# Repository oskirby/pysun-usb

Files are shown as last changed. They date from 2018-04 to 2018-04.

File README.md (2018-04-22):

PySUN-USB
=========
The PySUN is a USB dongle for IEEE 802.15.4 Smart Utility Networking protocols. This project is based around
an STM32F4-series microprocessor and the Atmel/Microchip AT86RF215 dual-band IEEE 802.15.4 transceiver. This
board also supports a Micropython programming environment. The two RF bands from the transceiver are combined
into a single antenna port using an RF diplexer.

This board is released as an Open Source Hardware project, including the full PCB design files from KiCAD.

Features
-----------
Attached to the STM32F4 microcontroller, are the following peripherals:
* AT86RF215 connected to SPI2.
* 32Mbit SPI flash connected to SPI1.
* RGB LED connected to PB0, PB1 and PB10.
* Tactile switch connected to BOOT0 and PB7.
* Power/status LED connected to PB6.

Castellated edges are provided, exposing:
* SPI1
* I2C1
* USART1
* RF215 FEA and FEB outputs

Power is provided by a 2MHz synchronous buck regulator and the clock reference is provided from a 26MHz TCXO.

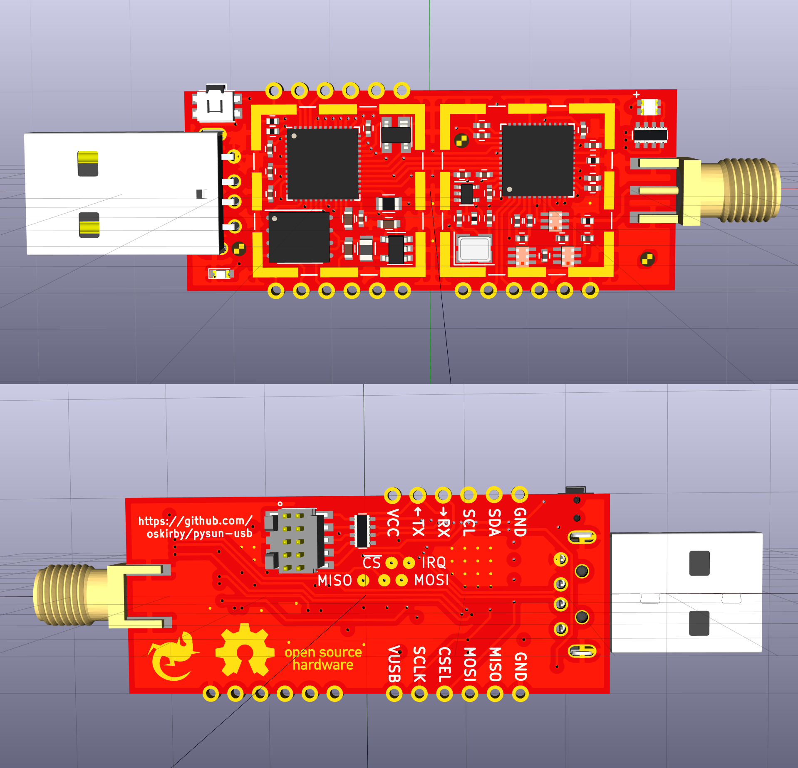
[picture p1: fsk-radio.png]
PySUN PCB Render


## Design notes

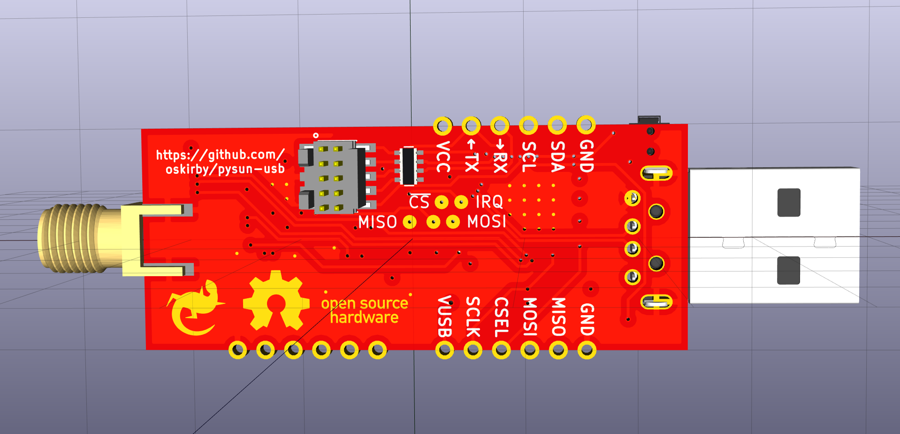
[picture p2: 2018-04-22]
fsk-radio-back.png

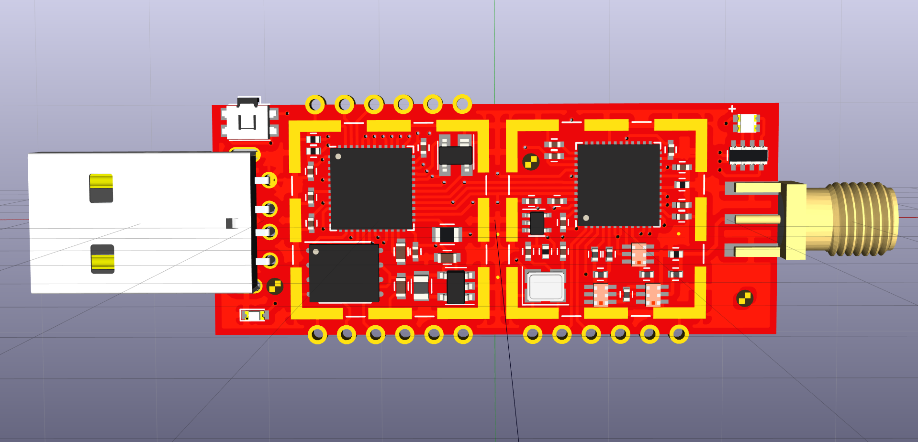
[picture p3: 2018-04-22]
fsk-radio-front.png

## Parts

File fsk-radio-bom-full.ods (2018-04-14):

Designator | Package | Quantity | Value | Manufacturer | Part Number | Substitutions | OPL | Notes
J5,J4 | 16.5mm Square RF Shield | 2 | RF_Shield_One_Piece | TE Connectivity | 2118707-4 | Y
C11,C7,C3 | C_0603 | 3 | 4.7uF | Yageo | CC0603KRX5RGBB475 | Y | 302010111 | Generic 0603 ceramic capacitor. Bulk capacitance for DCDC converter
J1 | CUI-UP2-AH-TH | 1 | USB_A | CUI | UP2-AH-1-TH | Y
IC4 | SOT-353_SC-70-5 | 1 | NC7SZ04 | NXP | NC7SZ04P5X | Y
IC6 | DFN-S-8-1EP_6x5mm_Pitch1.27mm | 1 | W25Q32BVZPIP | Winbond | W25Q32BVZPIP | Y | 310090078 | Generic SPI flash
X1 | Crystal_SMD_3225-4pin_3.2x2.5mm | 1 | TXETBLSANF-26 | Taitien | TXETBLSANF-26.000000 | N
R3,R4 | R_0402 | 2 | 470k | Yageo | RC0402FR-07470KL | Y | 301010069 | Generic 0402 resistor
C9,C15 | C_0402 | 2 | 1nF | Yageo | CC0402KRX7R9BB102 | Y | 302010005 | Generic 0402 ceramic capacitor
L1 | L_0603 | 1 | 2.2uH | TDK | VLF5010ST-2R2M2R0 | Y | 303010086 | 0805 Inductor. Substitutions okay if shielded with rated current >1A and SRF > 25MHz
B9 | Balun_0805 | 1 | 0896BM15E0025 | Johanson Technology | 0896BM15E0025E | N
B24 | Balun_0805 | 1 | 2450FB15A050 | Johanson Technology | 2450FB15A050E | N
C26 | L_0402 | 1 | 0.8pF | Johanson Dielectrics | 500R07S0R8BV4T | Y | 302010021 | 0402 NP0/C0G ceramic capacitor for RF filter
C27, C29 | L_0402 | 2 | 15pF | Johanson Dielectrics | 500R07S150JV4T | Y | 302010041 | 0402 NP0/C0G ceramic capacitor for RF filter
C31,C32 | L_0402 | 2 | 1.8pF | Johanson Dielectrics | 500R07S1R8BV4T | Y |  | 0402 NP0/C0G ceramic capacitor for RF filter
D1 | LED_0606_RGB | 1 | LED_RGB_ANODE | Line-On | LTST-C19HE1WT | Y
IC7 | Balun_0805 | 1 | DPX202700DT | TDK | DPX202700DT-4062A1 | N
L2 | L_0402 | 1 | 5.6nH | Johanson Technology | L-07C5N6SV6T | Y | 303010524 | 0402 inductor for RF filter
RN1 | R_Array_Concave_4x0603 | 1 | 330 | Bourns | CAT16-331J4LF | Y |  | Generic 1206 resistor array
J7 | SMA-Board-Edge | 1 | SMA | RF Solutions | CON-SMA-EDGE-S | Y |  | Board-edge SMA connector. Example: https://www.digikey.ca/product-detail/en/rf-solutions/CON-SMA-EDGE-S/CON-SMA-EDGE-S-ND/5845767
R17,R1 | R_0402 | 2 | 10k | Yageo | RC0402FR-0710KL | Y | 301010004 | Generic 0402 resistor
C10,C4,C5,C6,C8, C17, C20,C22,C19,C21,C23,C24,C25,C28 | C_0402 | 14 | 100n | Yageo | CC0402KRX7R8BB104 | Y | 302010024 | Generic 0402 ceramic capacitor. Bypass capacitance for digital supply
IC2 | QFN-48-1EP_7x7mm_Pitch0.5mm | 1 | AT86RF215 | Atmel | AT86RF215-ZU | N
IC1 | QFN-48-1EP_7x7mm_Pitch0.5mm | 1 | STM32F4xx-QFN48 | STMicro | STM32F413CGU6 | N
IC3 | SOT-23-5 | 1 | LM3671 | Texas Instruments | LM3671MF-3.3/NOPB | N
D2 | SOT-143 | 1 | PRTR5V0U2X | NXP | PRTR5V0U2X,215 | Y | 304050022 | ESD Protection diode for USB
D3 | LED_0603 | 1 | LED | Lite-On | LTST-C191KGKT | Y | 304090043 | Generic 0603 green LED
R2 | R_0402 | 1 | 330 | Yageo | RC0402FR-07330RL | Y | 301010466 | Generic 0402 resistor
SW1 | SW_SPST_EVQP7C | 1 | SW_Push |  | EVQ-P7C01P | N
R5 | R_0805 | 1 | 0 |  | RC0805JR-070RL | Y |  | Generic 0805 zero-ohm jumper
RN3 | R_Array_Concave_4x0603 | 1 | 22 |  | DNP
J3 | ftsh-105-01-dv | 1 | CONN_02X05 |  | DNP
FID2,FID1,FID2 | Fiducial_1mm_Dia_1.5mm_Outer_CopperTop | 3 | Fiducial_1mm_Dia_2.54mm_Outer_CopperTop |  | DNP

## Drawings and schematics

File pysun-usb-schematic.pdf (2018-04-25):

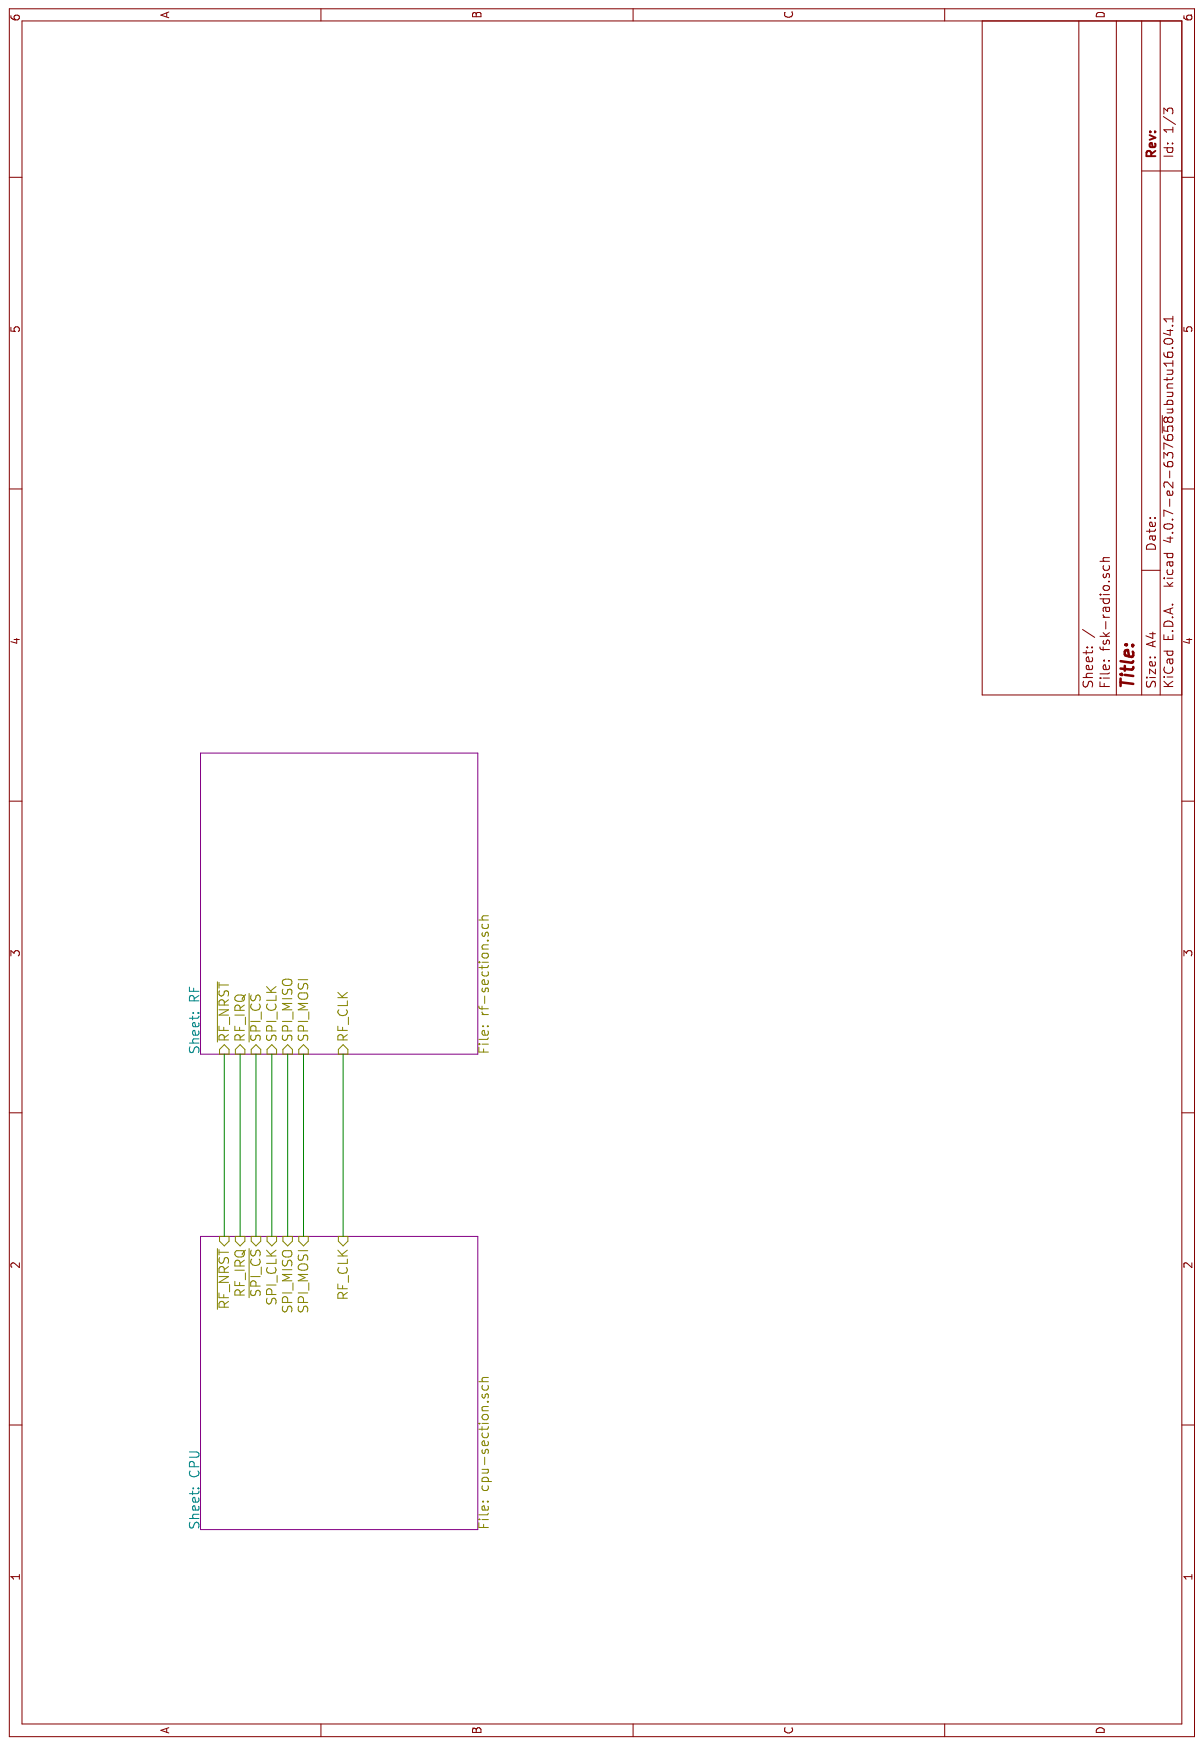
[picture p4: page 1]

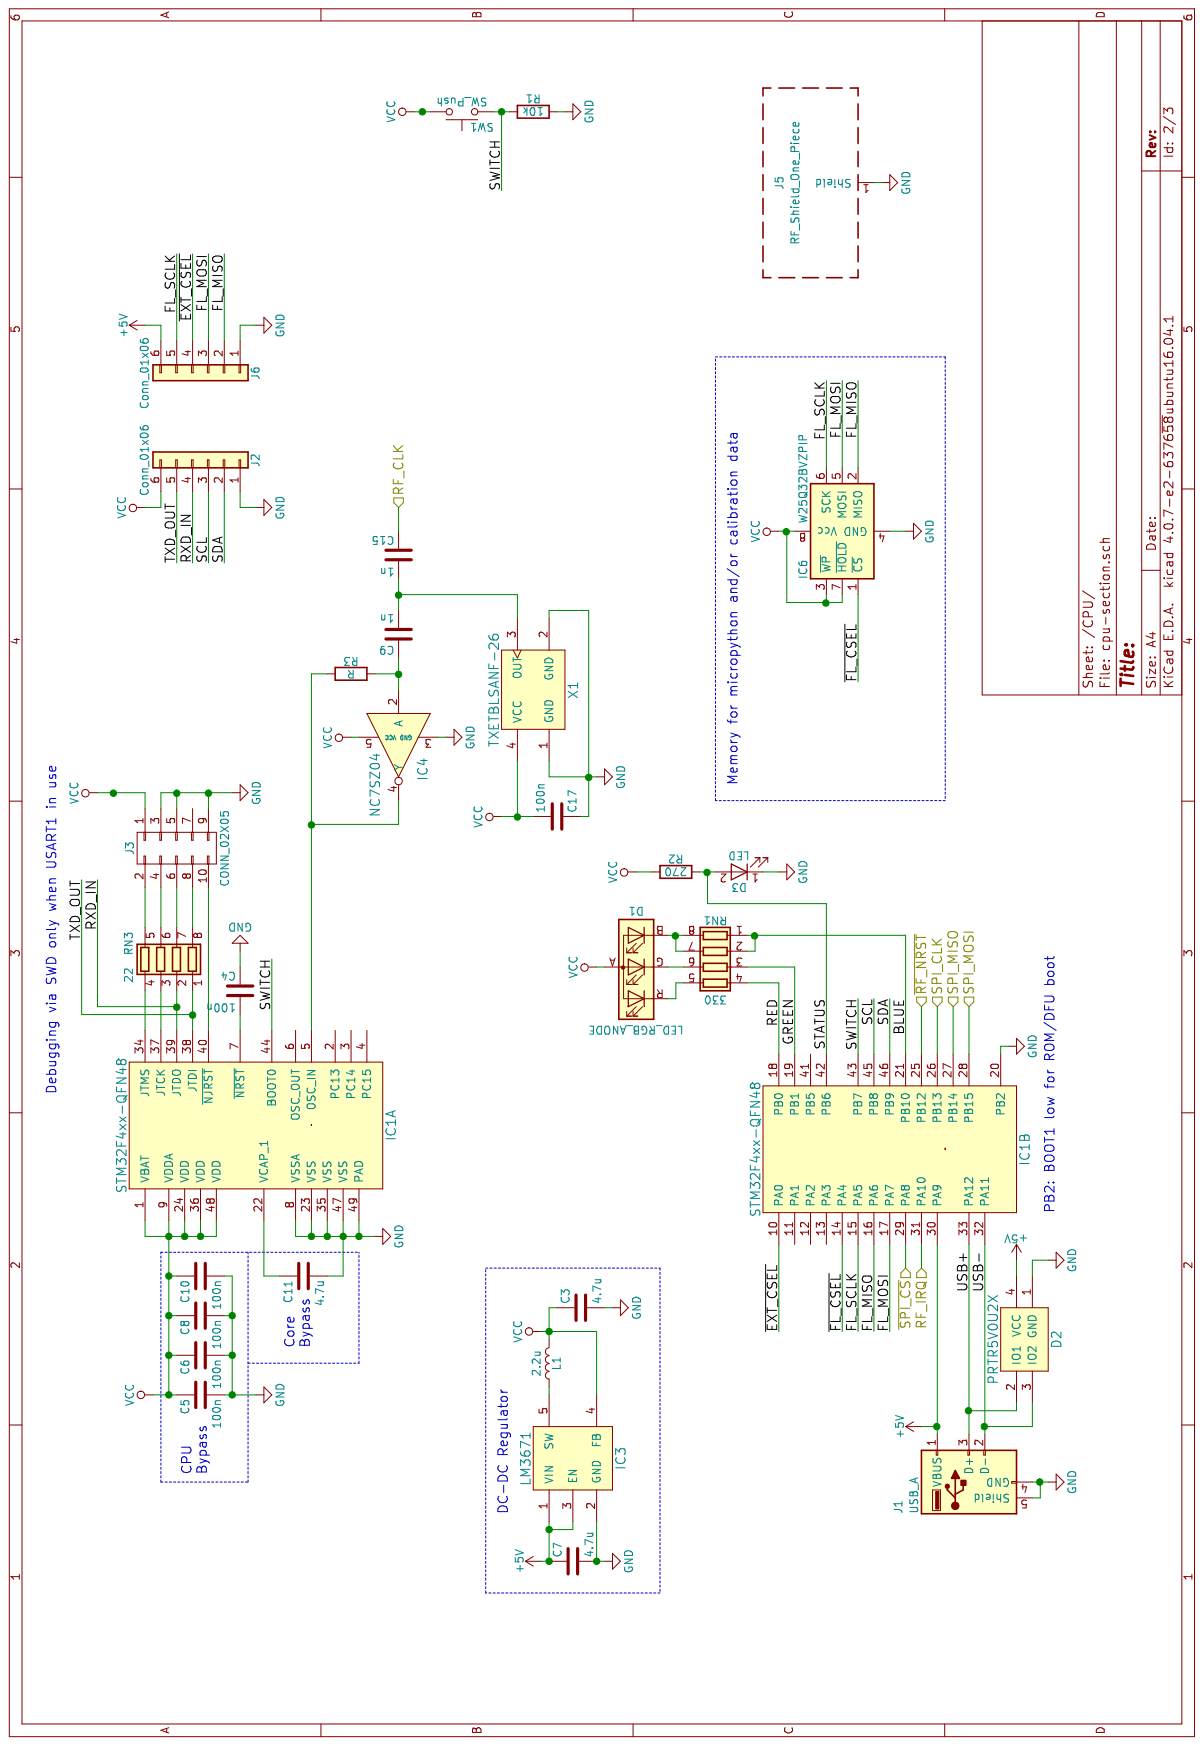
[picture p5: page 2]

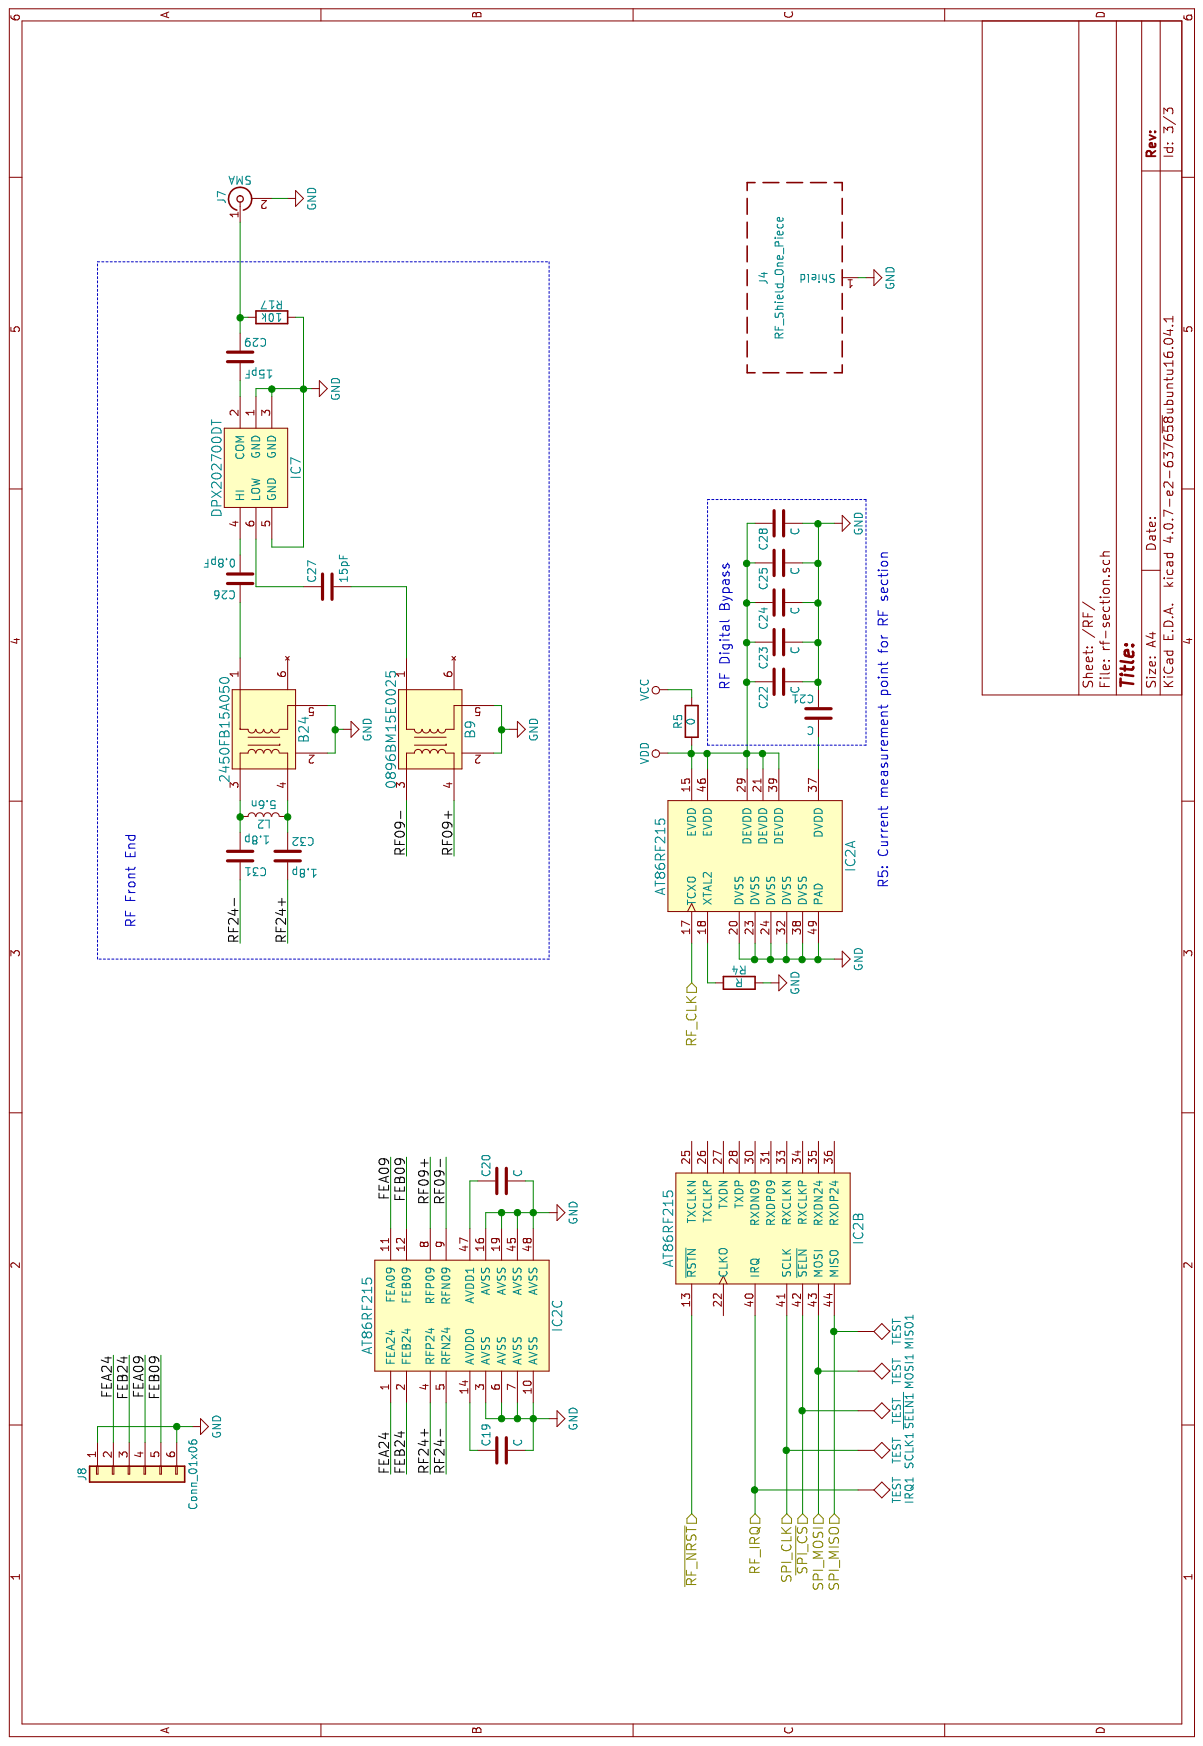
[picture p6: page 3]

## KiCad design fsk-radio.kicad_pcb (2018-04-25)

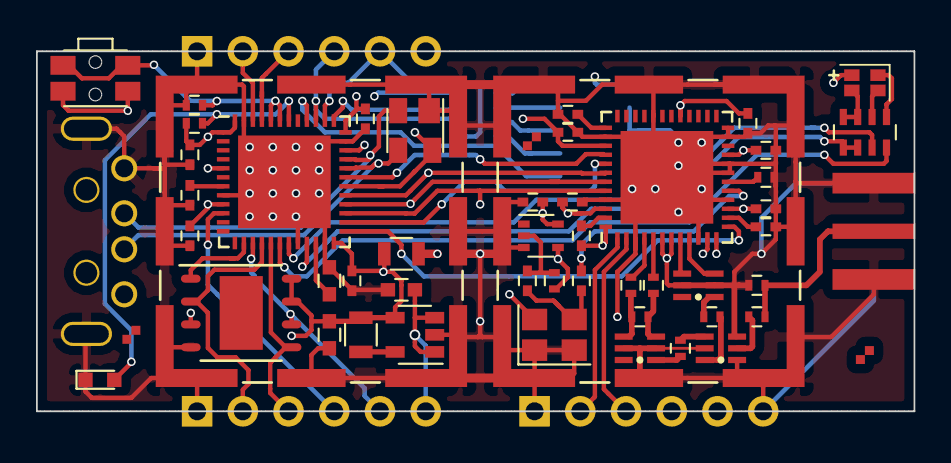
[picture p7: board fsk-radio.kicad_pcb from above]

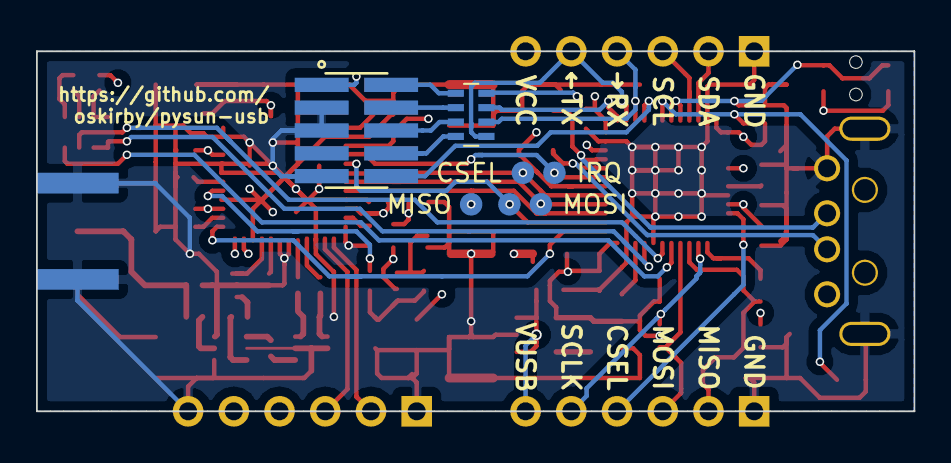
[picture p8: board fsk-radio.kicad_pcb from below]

Board: 4 copper layers, 48.8 x 20.0 mm, 65 parts (10 on the bottom side), 63 nets.

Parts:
B9: 0896BM15E0025; Balun_0805
B24: 2450FB15A050; Balun_0805
C3, C7, C11: 4.7u; C_0603
C4, C5, C6, C8, C10, C17: 100n; C_0402
C9, C15: 1n; C_0402
C19, C20, C21, C22, C23, C24, C25, C28: C; C_0402
C26: 0.8pF; L_0402
C27, C29: 15pF; L_0402
C31, C32: 1.8p; L_0402
D1: LED_RGB_ANODE; LED_0606_RGB
D2: PRTR5V0U2X; SOT-143
D3: LED; LED_0603
FID1, FID2, FID2#2: Fiducial_1mm_Dia_2.54mm_Outer_CopperTop; Fiducial_1mm_checker_1.5mm_mask
IC1: STM32F4xx-QFN48; QFN-48-1EP_7x7mm_Pitch0.5mm
IC2: AT86RF215; QFN-48-1EP_7x7mm_Pitch0.5mm
IC3: LM3671; SOT-23-5
IC4: NC7SZ04; SOT-353_SC-70-5
IC6: W25Q32BVZPIP; DFN-S-8-1EP_6x5mm_Pitch1.27mm
IC7: DPX202700DT; Balun_0805
IRQ1: TEST; Measurement_Point_Round-SMD-Pad_XSmall
J1: USB_A; CUI-UP2-AH-TH
J2, J6, J8: Conn_01x06; Castellated_Edge_6pin_2.54mm
J3: CONN_02X05; ftsh-105-01-dv
J4, J5: RF_Shield_One_Piece; Laird_Technologies_BMI-S-102_16.50x16.50mm_Paste
J7: SMA; SMA-Board-Edge
L1: 2.2u; L_0805
L2: 5.6n; L_0402
MISO1: TEST; Measurement_Point_Round-SMD-Pad_XSmall
MOSI1: TEST; Measurement_Point_Round-SMD-Pad_XSmall
R1, R17: 10k; R_0402
R2: 270; R_0402
R3, R4: R; R_0402
R5: 0; R_0805
RN1: 330; R_Array_Concave_4x0603
RN3: 22; R_Array_Concave_4x0603
SCLK1: TEST; Measurement_Point_Round-SMD-Pad_XSmall
SW1: SW_Push; SW_SPST_EVQP7C
X1: TXETBLSANF-26; Crystal_SMD_3225-4pin_3.2x2.5mm
exegin-logo: exegin-logo; exegin-logo-mask
oshw-silks: G***; oshw-mask
oshw-text: G***; oshw-text

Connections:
+5V: C7.1, D2.4, IC1.30, IC3.1, IC3.3, J1.1, J6.6
/CPU/BLUE: IC1.21, RN1.1, RN1.2
/CPU/FL_MISO: IC1.16, IC6.2, J6.2
/CPU/FL_MOSI: IC1.17, IC6.5, J6.3
/CPU/FL_SCLK: IC1.15, IC6.6, J6.5
/CPU/GREEN: IC1.19, RN1.3
/CPU/RED: IC1.18, RN1.4
/CPU/RF_CLK: C15.1, IC2.17
/CPU/RF_IRQ: IC1.31, IC2.40, IRQ1.1
/CPU/RXD_IN: IC1.39, J2.4, RN3.2
/CPU/SCL: IC1.45, J2.3
/CPU/SDA: IC1.46, J2.2
/CPU/SPI_CLK: IC1.26, IC2.41, SCLK1.1
/CPU/SPI_MISO: IC1.27, IC2.44, MISO1.1
/CPU/SPI_MOSI: IC1.28, IC2.43, MOSI1.1
/CPU/STATUS: D3.2, IC1.42, R2.2
/CPU/SWITCH: IC1.43, IC1.44, R1.1, SW1.2
/CPU/TXD_OUT: IC1.38, J2.5, RN3.1
/CPU/USB+: D2.2, IC1.33, J1.3
/CPU/USB-: D2.3, IC1.32, J1.2
/CPU/~EXT_CSEL: IC1.10, J6.4
/CPU/~FL_CSEL: IC1.14, IC6.1
/CPU/~RF_NRST: IC1.25, IC2.13
/CPU/~SPI_CS: IC1.29, IC2.42
/RF/FEA09: IC2.11, J8.4
/RF/FEA24: IC2.1, J8.2
/RF/FEB09: IC2.12, J8.5
/RF/FEB24: IC2.2, J8.3
/RF/RF09+: B9.4, IC2.8
/RF/RF09-: B9.3, IC2.9
/RF/RF24+: C32.2, IC2.4
/RF/RF24-: C31.1, IC2.5
GND: B9.2, B9.5, B24.2, B24.5, C3.2, C4.1, C5.2, C6.2, C7.2, C8.2, C10.2, C11.2, C17.1, C19.2, C20.2, C21.1, C22.2, C23.2, C24.2, C25.2, C28.2, D2.1, D3.1, IC1.8, IC1.20, IC1.23, IC1.35, IC1.47, IC1.49, IC2.3, IC2.6, IC2.7, IC2.10, IC2.16, IC2.19, IC2.20, IC2.23, IC2.24, IC2.32, IC2.38, IC2.45, IC2.48, IC2.49, IC3.2, IC4.3, IC6.4, IC7.1, IC7.3, IC7.5, J1.4, J1.5, J2.1, J3.3, J3.5, J3.9, J4.1, J5.1, J6.1, J7.2, J8.1, J8.6, R1.2, R4.2, R17.2, X1.1, X1.2
unnamed: B9.1, C27.2
unnamed: B24.1, C26.1
unnamed: B24.3, C31.2, L2.1
unnamed: B24.4, C32.1, L2.2
unnamed: C4.2, IC1.7
unnamed: C9.1, IC4.2, R3.2
unnamed: C11.1, IC1.22
unnamed: C9.2, C15.2, X1.3
unnamed: C19.1, IC2.14
unnamed: C20.1, IC2.47
unnamed: C21.2, IC2.37
unnamed: C26.2, IC7.4
unnamed: C27.1, IC7.6
unnamed: C29.1, J7.1, R17.1
unnamed: C29.2, IC7.2
unnamed: D1.B, RN1.7, RN1.8
unnamed: D1.G, RN1.6
unnamed: D1.R, RN1.5
unnamed: IC1.5, IC4.4, R3.1
unnamed: IC1.34, RN3.4
unnamed: IC1.37, RN3.3
unnamed: IC1.40, J3.10
unnamed: IC2.18, R4.1
unnamed: IC3.5, L1.1
unnamed: J3.2, RN3.5
unnamed: J3.4, RN3.6
unnamed: J3.6, RN3.7
unnamed: J3.8, RN3.8
VCC: C3.1, C5.1, C6.1, C8.1, C10.1, C17.2, D1.A, IC1.1, IC1.9, IC1.24, IC1.36, IC1.48, IC3.4, IC4.5, IC6.3, IC6.7, IC6.8, J2.6, J3.1, L1.2, R2.1, R5.2, SW1.1, X1.4
VDD: C22.1, C23.1, C24.1, C25.1, C28.1, IC2.15, IC2.21, IC2.29, IC2.39, IC2.46, R5.1

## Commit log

2017-08-16 Add KiCAD design files.
    [cpu-section.sch, fsk-radio.kicad_pcb, fsk-radio.sch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]
2017-08-16 Add 3D renders of PCB
2017-08-17 Cleanup silkscreen, add status LED.
    [cpu-section.sch, fsk-radio.kicad_pcb, rf-section.sch]
2017-08-26 Move CLKEN to BOOT1 pin to enable the TCXO during DFU boot.
    [cpu-section.sch, fsk-radio.kicad_pcb, rf-section.sch]
2017-08-30 Release for manufacturing.
    [fsk-radio.kicad_pcb]
2018-04-08 Rework and revise for revision 2.
    Major changes include:
    - Refactor clock heirarchy to improve RF performance.
    - Add pushbutton switch and SPI flash.
    - Shrink board dimensions down to make it more of a usable dongle.
    - Eliminate u.FL test points and SPI test pads.
    - Convert pin headers to castellated edges.
    [cpu-section.sch, fsk-radio.kicad_pcb, fsk-radio.sch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]
2018-04-12 Add more test features to the RF section.
    Split the RF and CPU power nets and connect them via a zero-ohm jumper
    to allow current sense, and add test pads for the RF SPI bus.
    [cpu-section.sch, fsk-radio.kicad_pcb, rf-section.sch]
2018-04-13 Release to manufacturing: rev2 prototype.
    [cpu-section.sch, fsk-radio.kicad_pcb, rf-section.sch]
2018-04-14 Add spreadsheet for BOM.
    [fsk-radio-bom-full.ods]
2018-04-22 Move 3D models into common repository.
    [fsk-radio.kicad_pcb]
2018-04-25 Final update to PCB for manufacturing release.
    Capacitor C22 moved to improve clearance with the RF shield and switch
    to using checker-mark pattern for fiducials. Other minor adjustments to
    the fab reference, silkscreen and paste layers.
    [cpu-section.sch, fsk-radio.kicad_pcb, rf-section.sch]
